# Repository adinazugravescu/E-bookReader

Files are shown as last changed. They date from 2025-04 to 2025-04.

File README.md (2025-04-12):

## Diagrama bloc

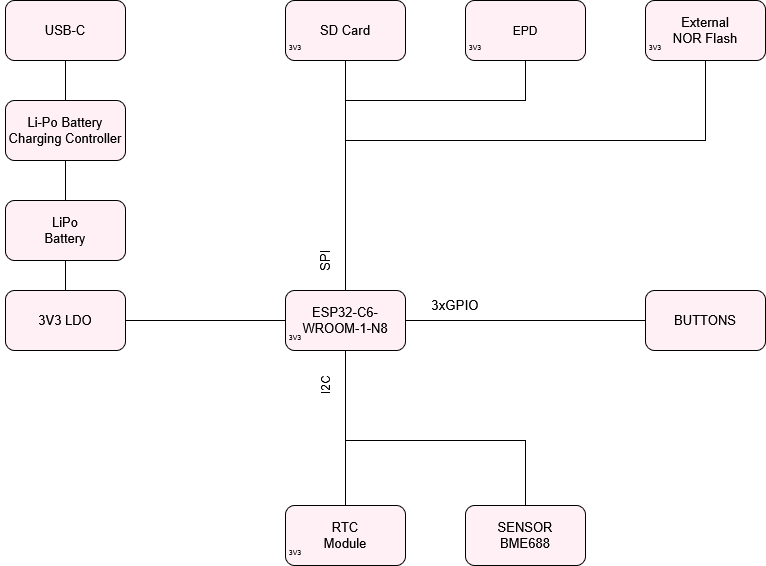
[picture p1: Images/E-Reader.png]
Diagrama bloc


##  Bill of Materials (BOM)

| Componenta/Modul | Link achizitie | Datasheet |
|---|---|---|
| Buton<br/> (*Model descarcat si adaptat*) | [Buy](https://componentsearchengine.com/prices/TSP1C-RA?manufacturer=KNITTER-SWITCH) | [Datasheet](https://docs.rs-online.com/1fd0/0900766b80e2c247.pdf) |
| Condensator 100nF | [Buy](https://ro.mouser.com/ProductDetail/KYOCERA-AVX/04026D104KAT2A?qs=LLG2yGGJ5NhILwMziGI8Xg%3D%3D) | [Datasheet](https://www.mouser.com/catalog/supplier/library/pdf/AVXSurfaceMountCeramic.pdf) |
| CPH3225A(C10_SUPERCAP) | [Buy](https://ro.mouser.com/ProductDetail/Seiko-Semiconductors/CPH3225A?qs=3etwrb1wR%252BhUOph6lAO7eg%3D%3D) | [Datasheet](https://ro.mouser.com/datasheet/2/360/Seiko_Instruments_MicroBattery_E_20230330_2024Jan_-3561061.pdf) |
| Condensator 4.7uF | [Buy](https://ro.mouser.com/ProductDetail/KEMET/C0402C475M7PACTU?qs=SzIX745sIXFB9Q9KfZhc4g%3D%3D) | [Datasheet](https://ro.mouser.com/datasheet/2/447/KEM_C1006_X5R_SMD-3316465.pdf) |
| Tantalum Condensator 100uF | [Buy](https://ro.mouser.com/ProductDetail/KYOCERA-AVX/TAJW107M010RNJ?qs=Wtp%252Bf%2FAeVqIH8v1VxV%252B1Rg%3D%3D) | [Datasheet](https://ro.mouser.com/datasheet/2/40/TAJ-3165264.pdf) |
| Condensator 1uF | [Buy](https://ro.mouser.com/ProductDetail/KYOCERA-AVX/04026D105KAT2A?qs=LLG2yGGJ5NgAzk5fb%252BnzGQ%3D%3D) | [Datasheet](https://ro.mouser.com/datasheet/2/40/cx5r_KGM-3223198.pdf) |
| Condensator 10uF | [Buy](https://www.digikey.com/en/products/detail/venkel/C0402X5R100-106MNP/12327194) | [Datasheet](https://venkelecd.com/partnumber/datasheet/C0402X5R100-106MNP) |
| CHG_LED | [Buy](https://www.kingbrightusa.com/distyPNInv.asp?sltSearch=distyInv&match=1&txtPartNo=APHM1608ECT) | [Datasheet](https://www.kingbrightusa.com/images/catalog/SPEC/APHM1608ECT.pdf) |
| USBLC6-2SC6Y | [Buy](https://ro.mouser.com/ProductDetail/STMicroelectronics/USBLC6-2SC6Y?qs=gNDSiZmRJS%2FOgDexvXkdow%3D%3D) | [Datasheet](https://ro.mouser.com/datasheet/2/389/usblc6_2sc6y-1852505.pdf) |
| PGB1010603MR | [Buy](https://ro.mouser.com/ProductDetail/Littelfuse/PGB1010603MR?qs=gu7KAQ731URLg4GSnNNN7Q%3D%3D) | [Datasheet](https://www.littelfuse.com/assetdocs/pulseguard-esd-suppressors-pgb1-datasheet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) |
| SD0805S020S1R0 | [Buy](https://ro.mouser.com/ProductDetail/KYOCERA-AVX/SD0805S020S1R0?qs=jCA%252BPfw4LHbpkAoSnwrdjw%3D%3D) | [Datasheet](https://ro.mouser.com/datasheet/2/40/schottky-3165252.pdf) |
| MBR0530 | [Buy](https://ro.mouser.com/ProductDetail/onsemi/MBR0530T1G?qs=3JMERSakeboS%2FFOxJUMWeg%3D%3D) | [Datasheet](https://www.onsemi.com/download/data-sheet/pdf/mbr0530t1-d.pdf) |
| Condensator 1uF/50V | [Buy](https://ro.mouser.com/ProductDetail/KYOCERA-AVX/06035D105MAT2A?qs=k4kUdCzLgS5%252BURKe1SOIeQ%3D%3D) | [Datasheet](https://ro.mouser.com/datasheet/2/40/cx5r_KGM-3223198.pdf) |
| Condensator 0.1uF/50V | [Buy](https://ro.mouser.com/ProductDetail/KYOCERA-AVX/04025C104JAT2A?qs=yqaQSyyJnNjAUYBPnTRwrw%3D%3D) | [Datasheet](https://ro.mouser.com/datasheet/2/40/AutoMLCC-2952695.pdf) |
| BD5229G-TR | [Buy](https://ro.mouser.com/ProductDetail/ROHM-Semiconductor/BD5229G-TR?qs=4kLU8WoGk0vvnhrrYwdszw%3D%3D) | [Datasheet](https://fscdn.rohm.com/en/products/databook/datasheet/ic/power/voltage_detector/bd52xxg-e.pdf) |
| XC6220A331MR-G | [Buy](https://ro.mouser.com/ProductDetail/Torex-Semiconductor/XC6220A331MR-G?qs=AsjdqWjXhJ8ZSWznL1J0gg%3D%3D) | [Datasheet](https://ro.mouser.com/datasheet/2/760/xc6220-3371556.pdf) |
| FH34SRJ-24S-0.5SH_99_ | [Buy](https://ro.mouser.com/ProductDetail/Hirose-Connector/FH34SRJ-24S-0.5SH99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) | [Datasheet](https://ro.mouser.com/datasheet/2/185/FH34SRJ_24S_0_5SH_99__CL0580_1255_6_99_2DDrawing_0-1615044.pdf) |
| USB4110-GF-A | [Buy](https://ro.mouser.com/ProductDetail/GCT/USB4110-GF-A?qs=KUoIvG%2F9IlYiZvIXQjyJeA%3D%3D) | [Datasheet](https://ro.mouser.com/datasheet/2/837/GCT_USB4110_Product_Drawing___20k_cycles-3455479.pdf) |
| QWIIC_RIGHT_ANGLE | [Buy](https://ro.mouser.com/ProductDetail/JST-Commercial/SM04B-SRSS-TBLFSN?qs=cdbOS8ANM9B3FdyA6cNU2A%3D%3D) | [Datasheet](https://ro.mouser.com/datasheet/2/564/eSR_SZ-3476820.pdf) |
| 112A-TAAR-R03_ATTEND | [Buy](https://www.tme.eu/ro/details/mcc-sdmicro/conectori-pentru-cartele/attend/112a-taar-r03/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) | [Datasheet](https://www.attend.com.tw/data/download/file/112A-TAAR-R03.pdf) |
| Bobina | [Buy](https://ro.mouser.com/ProductDetail/Wurth-Elektronik/744043680?qs=PGXP4M47uW6VkZq%252BkzjrHA%3D%3D) | [Datasheet](https://www.we-online.com/components/products/datasheet/744043680.pdf) |
| MCP73831 | [Buy](https://ro.mouser.com/ProductDetail/Microchip-Technology/MCP73831T-2ATI-OT?qs=yUQqVecv4qsZbioEUu%252B83g%3D%3D) | [Datasheet](https://ro.mouser.com/datasheet/2/268/MCP73831_Family_Data_Sheet_DS20001984H-3441711.pdf) |
| PFMF.050.1 | [Buy](https://ro.mouser.com/ProductDetail/Schurter/PFMF.050.2?qs=1auRipcfynCums5v1iucSA%3D%3D) | [Datasheet](https://ro.mouser.com/datasheet/2/358/typ_PFMF-1275918.pdf) |
| DMG2305UX-7 | [Buy](https://ro.mouser.com/ProductDetail/Diodes-Incorporated/DMG2305UX-7?qs=L1DZKBg7t5F%2FNBHrjfxC%252Bg%3D%3D) | [Datasheet](https://www.diodes.com/assets/Datasheets/DMG2305UX.pdf) |
| SI1308EDL-T1-GE3 | [Buy](https://ro.mouser.com/ProductDetail/Vishay-Semiconductors/SI1308EDL-T1-GE3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) | [Datasheet](https://www.vishay.com/docs/63399/si1308edl.pdf) |
| Rezistenta 10K | [Buy](https://www.digikey.com/en/products/detail/venkel/CR0402-10W-102JT/12332774) | [Datasheet](https://data.venkel.com/documents/cr-series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.) |
| Rezistenta 200 | [Buy](https://ro.mouser.com/ProductDetail/Vishay-Beyschlag/MCS0402MD2000BE100?qs=3SvaY9RawMJNVte4F12%252BZQ%3D%3D) | [Datasheet](https://www.vishay.com/docs/28952/mcs0402at-mct0603at-mcu0805at-mca1206at.pdf) |
| Rezistenta 100K | [Buy](https://www.digikey.com/en/products/detail/venkel/CR0402-16W-1003FT/12328296) | [Datasheet](https://octopart.com/datasheet/cr0402-16w-1003ft-venkel-16112934) |
| Rezistenta 2.2 | [Buy](https://www.digikey.com/en/products/detail/venkel/TFCR0402-16W-C-1002BT/12331302) | [Datasheet](https://data.venkel.com/documents/tfcr-series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.) |
| Rezistenta 5K1 | [Buy](https://ro.mouser.com/ProductDetail/YAGEO/RT0402BRD075K1L?qs=gY0y7AQI9SOxpEAvlEsiTQ%3D%3D) | [Datasheet](https://ro.mouser.com/datasheet/2/447/PYu_RT_1_to_0_01_RoHS_L_15-3461507.pdf) |
| Rezistenta 2K | [Buy](https://ro.mouser.com/ProductDetail/Bourns/CR0402AFX-2001GLF?qs=GedFDFLaBXEKjamDtfYtIQ%3D%3D) | [Datasheet](https://ro.mouser.com/datasheet/2/54/cr_a-1858337.pdf) |
| Rezistenta 0.47 | [Buy](https://ro.mouser.com/ProductDetail/Vishay-Beyschlag/MMA02040C4707JB000?qs=YmMt7wOBEV42V6C1Rc7zpg%3D%3D) | [Datasheet](https://www.vishay.com/docs/28713/melfprof.pdf) |
| Rezistenta 15 | [Buy](https://ro.mouser.com/ProductDetail/YAGEO/RT0402FRE0715RL?qs=BXCcY9r%252B08DFFpLSkPOIqQ%3D%3D) | [Datasheet](https://ro.mouser.com/datasheet/2/447/PYu_RT_1_to_0_01_RoHS_L_15-3461507.pdf) |
| BME688 | [Buy](https://ro.mouser.com/ProductDetail/Bosch-Sensortec/BME688?qs=IS%252B4QmGtzzqQoVDscqwx3A%3D%3D) | [Datasheet](https://ro.mouser.com/datasheet/2/783/bst_bme688_fl000-2307034.pdf) |
| W25Q512JVEIQ | [Buy](https://ro.mouser.com/ProductDetail/Winbond/W25Q512JVEIQ?qs=l7cgNqFNU1jw6svr3at6tA%3D%3D) | [Datasheet](https://ro.mouser.com/datasheet/2/949/Winbond_W25Q512JV_Datasheet-3240039.pdf) |
| ESP32-C6-WROOM-1-N8 | [Buy](https://ro.mouser.com/ProductDetail/Espressif-Systems/ESP32-C6-WROOM-1-N8?qs=8Wlm6%252BaMh8ST02Gmwp74cw%3D%3D) | [Datasheet](https://ro.mouser.com/datasheet/2/891/Espressif_ESP32_C6_WROOM_1__Datasheet_V0_1_PRELIMI-3239987.pdf) |
| DS3231SN# | [Buy](https://ro.mouser.com/ProductDetail/Analog-Devices-Maxim-Integrated/DS3231SN?qs=1eQvB6Dk1vhUlr8%2FOrV0Fw%3D%3D) | [Datasheet](https://ro.mouser.com/datasheet/2/609/DS3231-3421123.pdf) |
| MAX17048G+T10 | [Buy](https://ro.mouser.com/ProductDetail/Analog-Devices-Maxim-Integrated/MAX17048G%2bT10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) | [Datasheet](https://ro.mouser.com/datasheet/2/609/MAX17048_MAX17049-3469099.pdf) |
| Solder Jumper | [Buy](https://ro.mouser.com/ProductDetail/Vishay-Dale/CRCW04020000Z0EEHP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) | [Datasheet](https://www.vishay.com/docs/20043/crcwhpe3.pdf) |
| Test Pad | [Buy](https://www.digikey.com/en/products/detail/keystone-electronics/5006/255330) | [Datasheet](https://www.keyelco.com/userAssets/file/M65p56.pdf) |
##  Descriere functionalitate hardware

Proiectul este bazat pe un microcontroller **ESP32-C6-WROOM-1-N8**, alimentat printr-un LDO 3V3 dintr-o baterie Li-Po(1800 mAh). Alimentarea este gestionata de un circuit de incarcare **MCP73831** conectat la USB-C. ESP32-C6-WROOM-1-N8 controleaza toate componentele externe prin interfete standard SPI, I2C si GPIO:

- **E-paper Display** – conectat prin **SPI**
- **SD Card** – **SPI**, pentru stocare
- **NOR Flash** – **SPI**, memorie externa
- **RTC DS3231SN#** – conectat prin **I2C** pentru ceas de timp real
- **SENSOR2 BME688** – senzor de mediu conectat pe aceeasi magistrala **I2C**
- **RESET&BOOT/IO** – conectate prin GPIO
- **Qwiic/Stemma QT** – extensie I2C pentru senzori/modul aditionali
- **Test Pads** – pentru TX/RX UART + debugging hardware

Comunicarea cu display-ul si stocarea se face prin interfete rapide SPI. Toate componentele I2C partajeaza linia SDA si SCL, pentru a minimiza utilizarea pinilor.

**Specificatii electronice componente principale**

   - Microcontroller – ESP32-C6-WROOM-1-N8 CPU: 32-bit RISC-V single-core, frecventa maxima 160 MHz. Memorie interna: 320KB ROM, 512KB HP SRAM, 16KB LP SRAM. Conectivitate: Wi-Fi 6 si Bluetooth LE 5.0. Tensiune de operare: 3.3V. Consum de curent: 160–260 mA in mod activ, 3–20 mA in modem-sleep, 0.8 mA in light-sleep, 10 µA in deep-sleep, 2.5 µA in hibernare.

   - Display – E-paper 7.5": Display de tip ePaper, ales pentru consumul extrem de redus si lizibilitatea foarte buna in lumina naturala.

   - Memorie: Stocarea este realizata cu un card MicroSD si un cip NOR Flash de 64MB conectat pe aceeasi magistrala SPI.

   - Senzor ambiental – BME688: Senzor digital care masoara temperatura, umiditatea, presiunea si compozitia gazelor.Tensiune de alimentare: 1.71V – 3.6V. Consum: <1 mA in mod activ, <1 µA in mod sleep.

   - Regulator tensiune – XC6220A331MR-G: LDO pentru conversia tensiunii bateriei la 3.3V. Curent maxim de iesire: 700 mA. Tensiune de cadere: aprox. 250 mV la 500 mA.

   - Circuit incarcare baterie – MCP73831: Controller linear pentru incarcare acumulatori Li-Po. Tensiune intrare: 3.75V – 6V. Curent maxim programabil pana la 500 mA.

##  Utilizarea pinilor ESP32-C6

| Componenta | Pin ESP32-C6 | Functie | Justificare |
|---|---|---|---|
| **EPD** | IO7 | MOSI | Pin dedicat SPI pentru date, permite viteza mare de transfer |
| | IO6 | SCK | Clock SPI standard |
| | IO10 | EPD_CS | Linie de selectare pentru e-paper |
| | IO5 | EPD_DC | Selecteaza intre comanda si date trimise |
| | IO3 | EPD_BUSY | Citire stare de ocupare a display-ului |
| | IO23 | EPD_RST | Reset hardware |
| **SD Card** | IO6 | SCK | Linie separata CS pentru SD card |
| | IO2 | MISO | Linie unica pentru citirea datelor |
| | IO7 | MOSI | Linie partajata de scriere |
| | IO4 | SS_SD | Linie de chip select pentru SD card |
| **NOR Flash** | IO2 | MISO | Linie CS separata pentru memoria Flash |
| | IO7 | MOSI | Linie partajata de scriere |
| | IO11 | FLASH_CS | Selectare separata a chipului de memorie |
| | IO6 | SCK | Clock SPI comun |
| **RTC DS3231SN** | IO21 | SDA | Linie I2C standard pentru date |
| | IO22 | SCL | Linie I2C standard pentru ceas |
| | IO18 | RTC_RST | Reset software controlabil pentru RTC |
| | IO0 | INT_RTC | Wake-up de la RTC |
| | IO1 | 32KHZ | Iesire frecventa |
| **BME688** | IO21 | SDA | I2C partajat |
| | IO22 | SCL | I2C partajat |
| | IO19 | I2C_PW | Control alimentare senzor |
| **Qwiic** | IO21 / IO22  | SDA/SCL | ~ |
| **E-paper Power**  | IO20 | EPD_3V3_C | Activeaza alimentarea prin tranzistor |
| **BOOT Button** | IO9 | IO/BOOT | Pin standard pentru intrare in modul flash |
| **CHANGE Button**  | IO15 | IO/CHANGE | Permite comutarea intre modurile de functionare |
| **RESET Button** | EN | RESET | Pin hardware de reset (activ LOW) |
| **UART Debug** | GPIO16 | TX (TXD0) | Pentru debug/programare |
| | GPIO17 | RX (RXD0) | Pentru debug/programare |
| **USB** | IO12, IO13 | USB D- / D+ | Comunicare USB-C |

---
## Etapele implementarii proiectului

1. **Realizarea schematicului**  
   Am creat schema electrica pe baza modelului oferit, utilizand componentele si simbolurile din biblioteca furnizata. Am avut grija sa respect toate cerintele tehnice si sa evit erorile de ERC. Avertismentele ramase au fost acceptate, deoarece reies direct din structura impusa de model.

2. **Proiectarea PCB-ului**  
   Am trecut in modul PCB, unde am plasat toate componentele pe stratul top, conform pozitiei si dimensiunilor impuse. Am decupat antena modulului ESP32-C6 si am pozitionat corect toate elementele, astfel incat sa incapa in carcasa.

3. **Rutarea si planul de masa**  
   Am realizat rutarea pe baza constrangerilor din tema, am aplicat plan de masa atat pe stratul top, cat si pe stratul bottom, si am adaugat via stitching intre cele doua straturi pentru integritate electrica .

4. **Adaugarea informatiilor de productie**  
   Am etichetat toate componentele pe silkscreen pentru o vizualizare clara in 3D si pentru productie.

5. **Integrarea modelelor 3D**  
   Am importat modelele 3D corespunzatoare pentru fiecare componenta in parte si le-am creat modelele 3D.

6. **Modelarea carcasei**  
   Am adaptat carcasa astfel incat placa sa se potriveasca perfect in interior, respectand cerintele mecanice de montaj.

7. **Constructia componentelor externe**  
   Am construit modelul 3D al bateriei si al display-ului conform dimensiunilor si detaliilor din datasheet-urile oferite.

###  Probleme intampinate

- Gasirea unui model 3D compatibil cu footprint-ul butonului a fost dificila, asa ca am modificat manual un model descarcat.
- In schematic, anumite warning-uri au fost acceptate deoarece erau implicite in structura designului cerut.
- Au fost acceptate cele doua erori DRC aparute la mufa USB, conform instructiunilor primite.

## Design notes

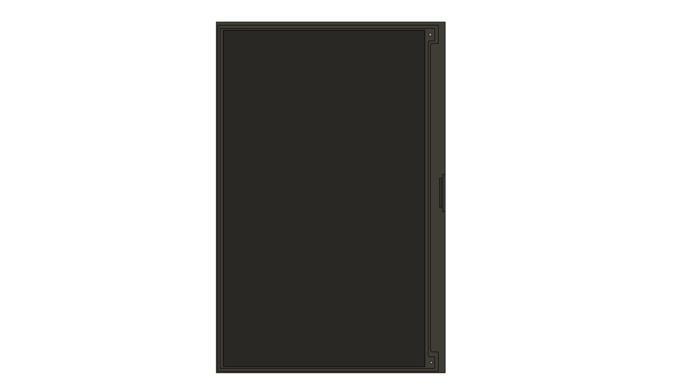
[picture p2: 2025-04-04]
Images/DISPLAY(1).png

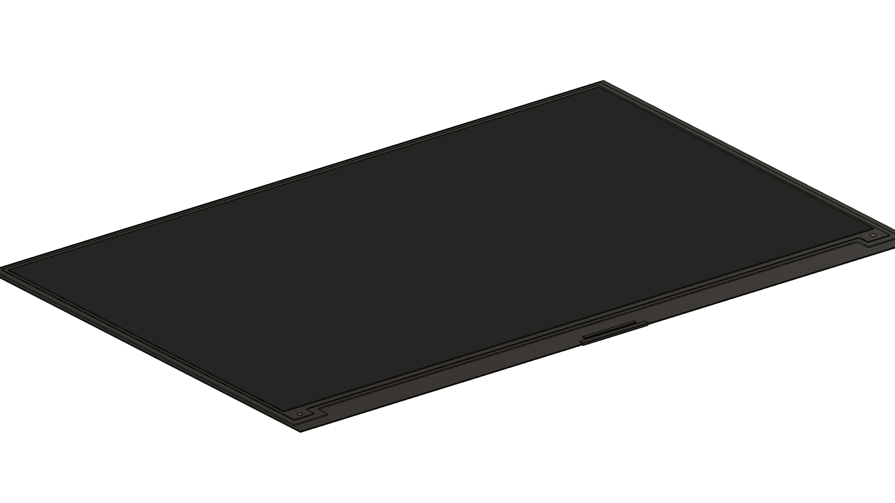
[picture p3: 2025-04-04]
Images/DISPLAY(2).png

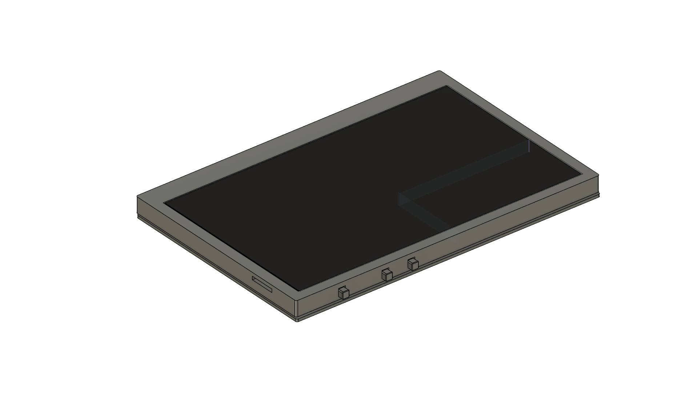
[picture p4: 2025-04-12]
Images/DEVICE(1).png

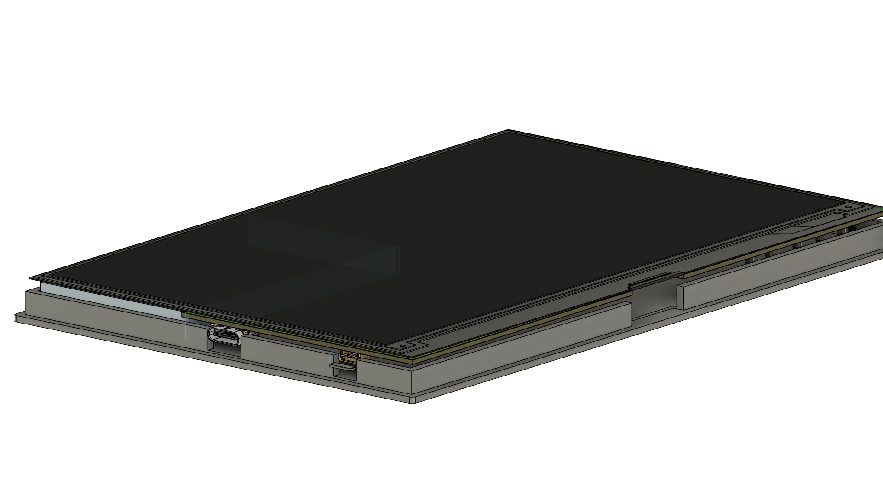
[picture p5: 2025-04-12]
Images/DEVICE(5).png

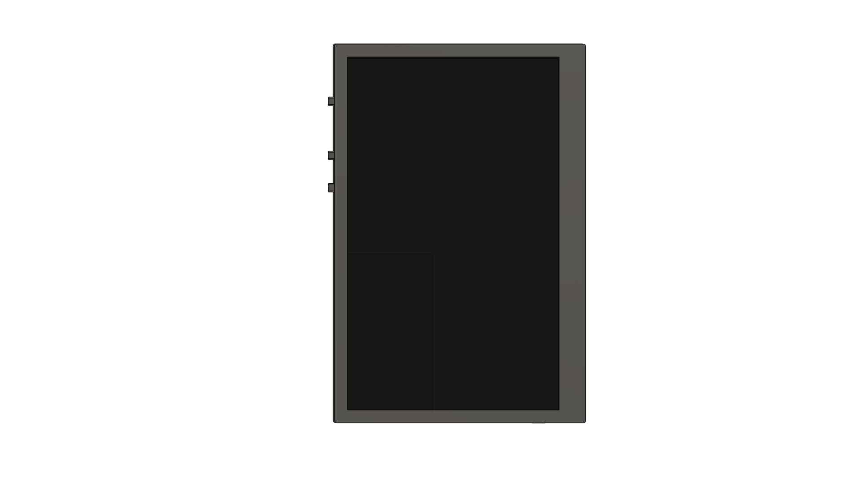
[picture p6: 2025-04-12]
Images/DEVICE(3).png

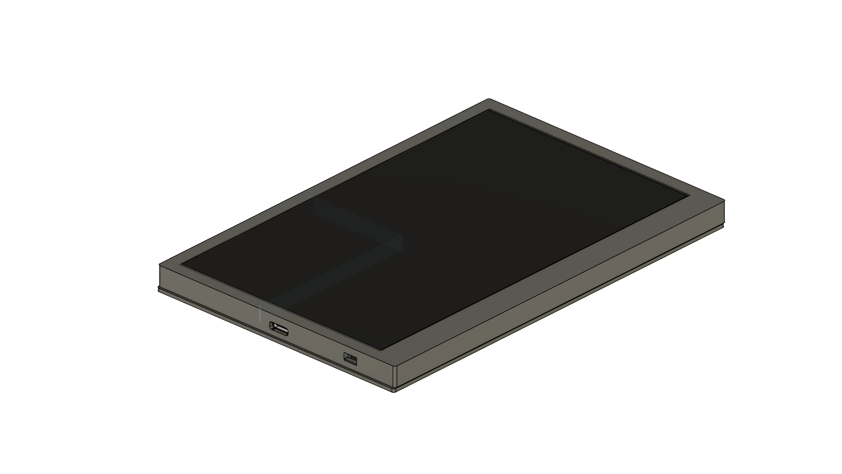
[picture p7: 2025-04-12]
Images/DEVICE(2).png

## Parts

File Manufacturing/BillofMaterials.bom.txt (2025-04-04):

Designator                      Comment Footprint
BOOT_BUTTON	49.03	108.83	180.00	BUTTON_CUSYOMV1	MYBUTTON
C1	155.24	5.93	90.00	100nF	EAGLE-LTSPICE_C0402
C10	67.74	108.31	90.00	100nF	EAGLE-LTSPICE_C0402
C10_SUPERCAP	96.49	50.94	270.00	CPH3225A	CAPCP3225X100N
C1_BAT	121.93	51.15	0.00	4.7uF	EAGLE-LTSPICE_C0402
C1_BAT1	122.28	38.37	180.00	4.7uF	EAGLE-LTSPICE_C0402
C1_BAT2	134.52	41.37	90.00	4.7uF	EAGLE-LTSPICE_C0402
C2	156.72	5.93	90.00	100nF	EAGLE-LTSPICE_C0402
C2_BAT	133.64	52.85	90.00	4.7uF	EAGLE-LTSPICE_C0402
C3	131.31	40.30	270.00	100uF TANT	RCL_CT3528
C4	92.31	30.59	90.00	4.7uF/25V	EAGLE-LTSPICE_C0402
C4_USB	152.63	48.07	0.00	100nF	EAGLE-LTSPICE_C0402
C5	27.61	108.31	90.00	1uF	EAGLE-LTSPICE_C0402
C5_USB	152.64	46.57	0.00	4.7uF	EAGLE-LTSPICE_C0402
C6	45.30	108.21	90.00	100nF	EAGLE-LTSPICE_C0402
C7	79.79	22.63	0.00	10uF	EAGLE-LTSPICE_C0402
C8	87.48	47.33	0.00	100nF	EAGLE-LTSPICE_C0402
C9	7.06	99.53	90.00	100nF	EAGLE-LTSPICE_C0402
CHANGE_BUTTON	64.06	108.83	180.00	BUTTON_CUSYOMV1	MYBUTTON
CHG_LED	125.44	51.15	90.00		ADAFRUIT_CHIP-LED0603
C_DELAY	52.57	100.99	90.00	100nF	EAGLE-LTSPICE_C0402
D1	151.98	50.97	0.00	USBLC6-2SC6Y	SOT95P280X145-6N
D10	46.22	37.77	270.00	PGB1010603MR	DIOC1608X36N
D11	49.70	37.77	90.00	PGB1010603MR	DIOC1608X36N
D12	51.58	37.77	90.00	PGB1010603MR	DIOC1608X36N
D2	121.49	41.58	90.00	ESP32_WROVER_AVX---SD0805S020S1R0_AVX_SD0805S020S1R0_0_0AVX_SD0805S020S1R0_0_0	ESP32_WROVER_AVX---SD0805S020S1R0_AVX_SD0805S020S1R0_0
D3	88.56	26.57	0.00	MBR0530	SOD3716X135N
D4	81.52	33.78	180.00	MBR0530	SOD3716X135N
D5	88.54	29.98	180.00	MBR0530	SOD3716X135N
D6	74.28	21.07	0.00	PGB1010603MR	DIOC1608X36N
D7	88.24	63.28	0.00	ESP32_WROVER_AVX---SD0805S020S1R0_AVX_SD0805S020S1R0_0_0AVX_SD0805S020S1R0_0_0	ESP32_WROVER_AVX---SD0805S020S1R0_AVX_SD0805S020S1R0_0
D8	15.26	98.77	0.00	PGB1010603MR	DIOC1608X36N
D9	35.94	46.77	90.00	PGB1010603MR	DIOC1608X36N
EPD_C1	68.85	19.77	90.00	1uF/50V	EAGLE-LTSPICE_C0402
EPD_C10	85.51	19.89	90.00	1uF/50V	EAGLE-LTSPICE_C0402
EPD_C11	87.09	19.89	90.00	1uF/50V	EAGLE-LTSPICE_C0402
EPD_C12	88.75	19.89	90.00	1uF/50V	EAGLE-LTSPICE_C0402
EPD_C2	70.48	19.75	90.00	1uF/50V	EAGLE-LTSPICE_C0402
EPD_C5	77.05	19.89	90.00	0.1uF/50V	EAGLE-LTSPICE_C0402
EPD_C6	78.69	19.85	90.00	1uF/50V	EAGLE-LTSPICE_C0402
EPD_C7	80.40	19.85	90.00	1uF/50V	EAGLE-LTSPICE_C0402
EPD_C8	82.11	19.85	90.00	1uF/50V	EAGLE-LTSPICE_C0402
EPD_C9	83.72	19.85	90.00	1uF/50V	EAGLE-LTSPICE_C0402
IC1	49.25	100.67	0.00	BD5229G-TR	SOT95P280X125-5N
IC4	126.03	41.39	0.00	XC6220A331MR-G	SOT95P280X120-5N
J1	83.07	13.94	0.00	FH34SRJ-24S-0.5SH_99_	FH34SRJ24S05SH99
J2	165.93	54.30	90.00	SAMACSYS_PARTS_USB4110-GF-A	SAMACSYS_PARTS_USB4110GFA
J3	166.35	19.30	90.00	QWIIC_RIGHT_ANGLE	JST04_1MM_RA
J4	9.09	88.95	270.00	112A-TAAR-R03_ATTEND	112ATAARR03ATTEND
L1	81.50	28.20	270.00	68uH	IND_4828-WE-TPC_WRE
MCP73831	129.15	50.59	90.00	ESP32_WROVER_SPARKFUN-IC-POWER_MCP73831	ESP32_WROVER_SPARKFUN-IC-POWER_SOT23-5
PFMF.050.1	151.04	43.50	0.00	ESP32C6_VARISTORCN1812	ESP32C6_VARISTOR_CT/CN1812
Q1	136.06	47.31	0.00	20V/4.2A/52mΩ/1.4W	ESP32_WROVER_SPARKFUN-DISCRETESEMI_SOT23-3
Q2	76.53	23.76	270.00	20V/4.2A/52mΩ/1.4W	ESP32_WROVER_SPARKFUN-DISCRETESEMI_SOT23-3
Q3	63.69	18.38	90.00	SI1308EDL-T1-GE3	SOT65P210X110-3N
R1	19.45	40.33	90.00	10K	ESP32_WROVER_EAGLE-LTSPICE_R0402
R10	8.43	99.53	90.00	10K	ESP32_WROVER_EAGLE-LTSPICE_R0402
R1_BAT	125.25	49.55	0.00	200	ESP32_WROVER_EAGLE-LTSPICE_R0402
R1_PINH	152.16	5.97	90.00	10K	ESP32_WROVER_EAGLE-LTSPICE_R0402
R1_PINH1	88.26	61.64	0.00	10K	ESP32_WROVER_EAGLE-LTSPICE_R0402
R1_PWRUSB	119.55	41.64	90.00	100K	ESP32_WROVER_EAGLE-LTSPICE_R0402
R2	62.73	13.21	0.00	2.2	ESP32_WROVER_EAGLE-LTSPICE_R0402
R2-PINH	153.72	5.97	90.00	10K	ESP32_WROVER_EAGLE-LTSPICE_R0402
R2-PINH1	92.43	60.19	90.00	10K	ESP32_WROVER_EAGLE-LTSPICE_R0402
R2-USB	154.98	52.83	90.00	5K1	ESP32_WROVER_EAGLE-LTSPICE_R0402
R2-USB1	147.90	51.17	90.00	5K1	ESP32_WROVER_EAGLE-LTSPICE_R0402
R2_BAT	127.86	46.85	90.00	2K	ESP32_WROVER_EAGLE-LTSPICE_R0402
R3	65.11	12.23	90.00	0.47	ESP32_WROVER_EAGLE-LTSPICE_R0402
R4	66.89	17.11	0.00	10K	ESP32_WROVER_EAGLE-LTSPICE_R0402
R5	33.81	46.78	268.50	10K	ESP32_WROVER_EAGLE-LTSPICE_R0402
R6	46.43	34.21	90.00	10K	ESP32_WROVER_EAGLE-LTSPICE_R0402
R7	49.65	34.21	90.00	10K	ESP32_WROVER_EAGLE-LTSPICE_R0402
R8	51.67	34.21	90.00	10K	ESP32_WROVER_EAGLE-LTSPICE_R0402
R9	71.99	23.81	90.00	10K	ESP32_WROVER_EAGLE-LTSPICE_R0402
RESET_BUTTON	23.95	108.83	180.00	BUTTON_CUSYOMV1	MYBUTTON
R_BOOT	52.71	108.31	90.00	10K	ESP32_WROVER_EAGLE-LTSPICE_R0402
R_CAPACITOR	93.55	50.64	90.00	15	ESP32_WROVER_EAGLE-LTSPICE_R0402
R_CHANGE	60.42	108.24	90.00	10K	ESP32_WROVER_EAGLE-LTSPICE_R0402
R_CL1	73.86	23.73	90.00	10K	ESP32_WROVER_EAGLE-LTSPICE_R0402
R_RESET	20.29	108.31	90.00	10K	ESP32_WROVER_EAGLE-LTSPICE_R0402
SENSOR2	154.72	11.32	90.00	BME688	ESP32_WROVER_BME680_PSON80P300X300X100-8N
SJ1	62.36	11.29	0.00		SJ
TP1	3.01	30.69	0.00	TPTP20R	TP20R
TP10	14.38	2.91	0.00	TPTP20R	TP20R
TP11	22.09	2.89	0.00	TPTP20R	TP20R
TP12	30.03	3.01	0.00	TPTP20R	TP20R
TP13	39.68	3.11	0.00	TPTP20R	TP20R
TP14	143.13	64.01	0.00	TPTP20R	TP20R
TP15	84.68	96.61	0.00	TPTP20R	TP20R
TP16	84.93	90.21	0.00	TPTP20R	TP20R
TP17	47.08	2.91	0.00	TPTP20R	TP20R
TP2	2.88	25.79	0.00	TPTP20R	TP20R
TP3	148.25	63.99	0.00	TPTP20R	TP20R
TP4	81.37	102.89	0.00	TPTP20R	TP20R
TP5	87.99	102.89	0.00	TPTP20R	TP20R
TP6	3.01	20.29	0.00	TPTP20R	TP20R
TP7	6.63	16.49	0.00	TPTP20R	TP20R
TP8	6.75	11.39	0.00	TPTP20R	TP20R
TP9	6.87	5.99	0.00	TPTP20R	TP20R
U1	39.59	52.96	0.00	W25Q512JVEIQ	SON127P600X800X80-9N
U2	16.30	52.71	90.00	ESP32-C6-WROOM-1-N8	XCVR_ESP32-C6-WROOM-1-N8
U3	84.85	54.90	270.00	DS3231SN#	SOIC127P1032X265-16N
U4	139.04	53.12	0.00	MAX17048G+T10	SON50P200X200X80-9N

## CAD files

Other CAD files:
Mechanical/E-Reader(PCB+BATTERY+DISPLAY+CASE).f3z

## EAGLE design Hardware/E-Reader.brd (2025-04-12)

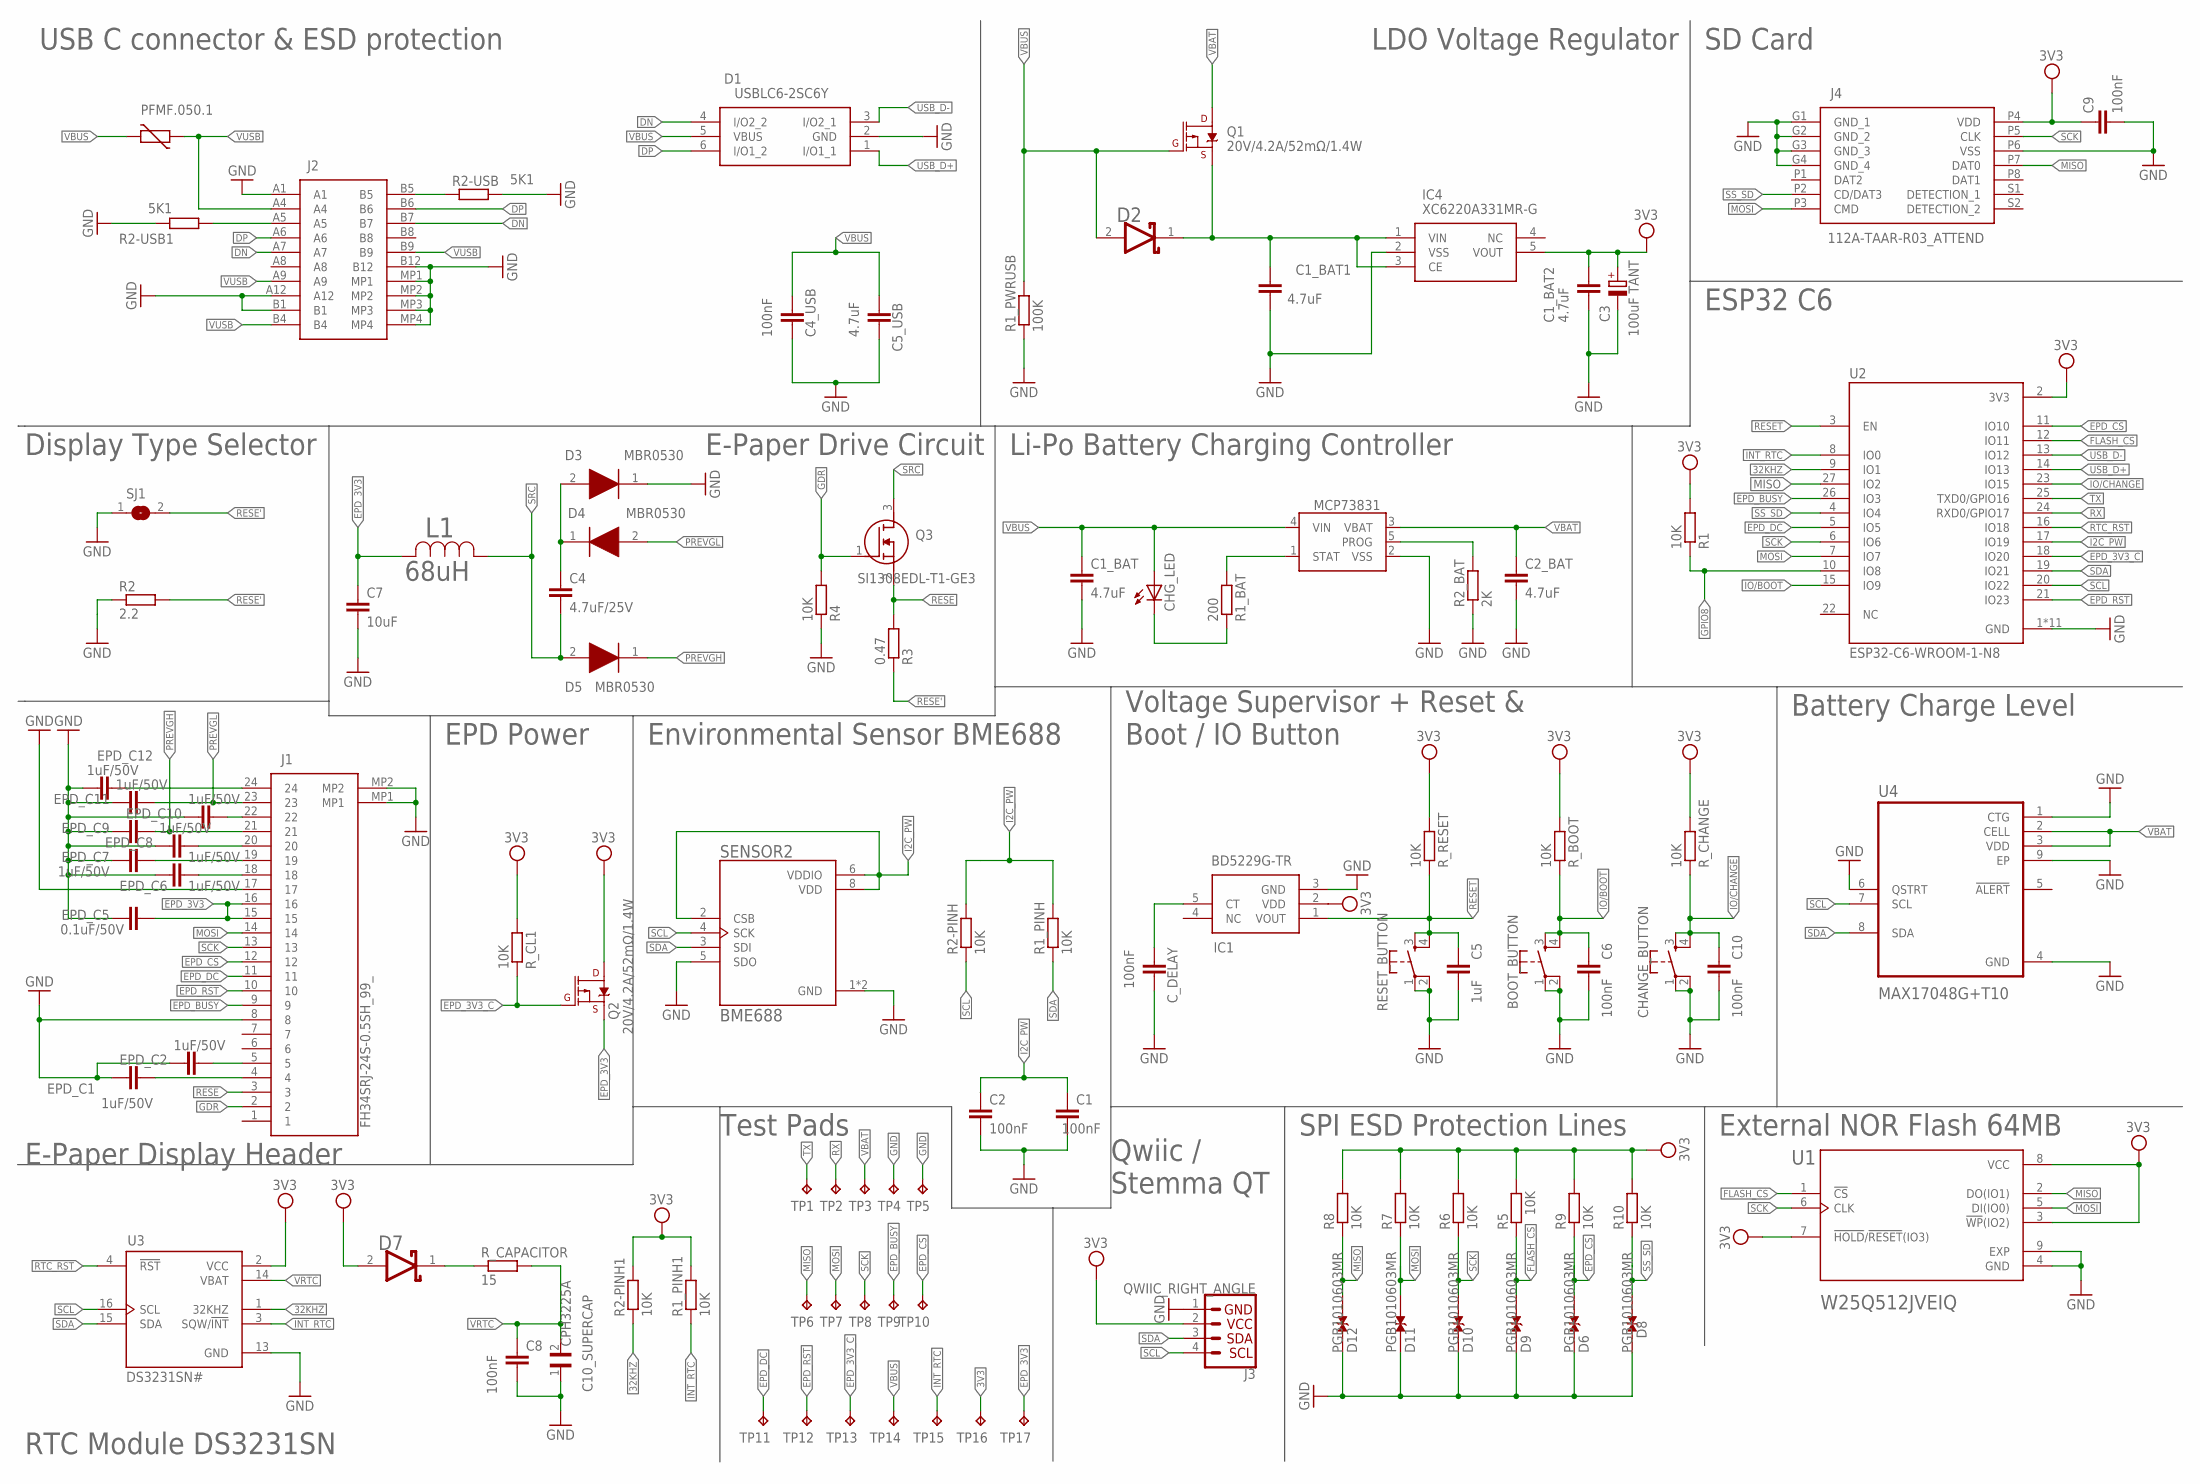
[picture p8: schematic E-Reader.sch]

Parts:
BOOT_BUTTON: BUTTON_CUSYOMV1; MYBUTTON
C1, C2, C4_USB, C6, C8, C9, C10: 100nF; EAGLE-LTSPICE_C0402
C1_BAT, C1_BAT1, C1_BAT2, C2_BAT, C5_USB: 4.7uF; EAGLE-LTSPICE_C0402
C3: 100uF TANT; RCL_CT3528
C4: 4.7uF/25V; EAGLE-LTSPICE_C0402
C5: 1uF; EAGLE-LTSPICE_C0402
C7: 10uF; EAGLE-LTSPICE_C0402
C10_SUPERCAP: CPH3225A; CAPCP3225X100N
CHANGE_BUTTON: BUTTON_CUSYOMV1; MYBUTTON
CHG_LED: ADAFRUIT_LEDCHIP-LED0603; ADAFRUIT_CHIP-LED0603
C_DELAY: 100nF; EAGLE-LTSPICE_C0402
D1: USBLC6-2SC6Y; SOT95P280X145-6N
D2, D7: ESP32_WROVER_AVX---SD0805S020S1R0_AVX_SD0805S020S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; ESP32_WROVER_AVX---SD0805S020S1R0_AVX_SD0805S020S1R0_0
D3, D4, D5: MBR0530; SOD3716X135N
D6, D8, D9, D10, D11, D12: PGB1010603MR; DIOC1608X36N
EPD_C1, EPD_C2, EPD_C6, EPD_C7, EPD_C8, EPD_C9, EPD_C10, EPD_C11, EPD_C12: 1uF/50V; EAGLE-LTSPICE_C0402
EPD_C5: 0.1uF/50V; EAGLE-LTSPICE_C0402
IC1: BD5229G-TR; SOT95P280X125-5N
IC4: XC6220A331MR-G; SOT95P280X120-5N
J1: FH34SRJ-24S-0.5SH_99_; FH34SRJ24S05SH99
J2: SAMACSYS_PARTS_USB4110-GF-A; SAMACSYS_PARTS_USB4110GFA
J3: QWIIC_RIGHT_ANGLE; JST04_1MM_RA
J4: 112A-TAAR-R03_ATTEND; 112ATAARR03ATTEND
L1: 68uH; IND_4828-WE-TPC_WRE
MCP73831: ESP32_WROVER_SPARKFUN-IC-POWER_MCP73831; ESP32_WROVER_SPARKFUN-IC-POWER_SOT23-5
PFMF.050.1: ESP32C6_VARISTORCN1812; ESP32C6_VARISTOR_CT/CN1812
Q1, Q2: 20V/4.2A/52mΩ/1.4W; ESP32_WROVER_SPARKFUN-DISCRETESEMI_SOT23-3
Q3: SI1308EDL-T1-GE3; SOT65P210X110-3N
R1, R1_PINH, R1_PINH1, R2-PINH, R2-PINH1, R4, R5, R6, R7, R8, R9, R10: 10K; ESP32_WROVER_EAGLE-LTSPICE_R0402
R1_BAT: 200; ESP32_WROVER_EAGLE-LTSPICE_R0402
R1_PWRUSB: 100K; ESP32_WROVER_EAGLE-LTSPICE_R0402
R2: 2.2; ESP32_WROVER_EAGLE-LTSPICE_R0402
R2-USB, R2-USB1: 5K1; ESP32_WROVER_EAGLE-LTSPICE_R0402
R2_BAT: 2K; ESP32_WROVER_EAGLE-LTSPICE_R0402
R3: 0.47; ESP32_WROVER_EAGLE-LTSPICE_R0402
RESET_BUTTON: BUTTON_CUSYOMV1; MYBUTTON
R_BOOT: 10K; ESP32_WROVER_EAGLE-LTSPICE_R0402
R_CAPACITOR: 15; ESP32_WROVER_EAGLE-LTSPICE_R0402
R_CHANGE: 10K; ESP32_WROVER_EAGLE-LTSPICE_R0402
R_CL1: 10K; ESP32_WROVER_EAGLE-LTSPICE_R0402
R_RESET: 10K; ESP32_WROVER_EAGLE-LTSPICE_R0402
SENSOR2: BME688; ESP32_WROVER_BME680_PSON80P300X300X100-8N
SJ1: SJ
TP1, TP2, TP3, TP4, TP5, TP6, TP7, TP8, TP9, TP10, TP11, TP12, TP13, TP14, TP15, TP16, TP17: TPTP20R; TP20R
U1: W25Q512JVEIQ; SON127P600X800X80-9N
U2: ESP32-C6-WROOM-1-N8; XCVR_ESP32-C6-WROOM-1-N8
U3: DS3231SN#; SOIC127P1032X265-16N
U4: MAX17048G+T10; SON50P200X200X80-9N

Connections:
3V3: C1_BAT2.1, C3.+, C9.1, D7.2 (ANODE), IC1.2 (VDD), IC4.5 (VOUT), J3.2, J4.P4 (VDD), Q2.3 (D), R1.2, R1_PINH1.2, R2-PINH1.2, R5.2, R6.2, R7.2, R8.2, R9.2, R10.2, R_BOOT.2, R_CHANGE.2, R_CL1.2, R_RESET.2, TP16.TP, U1.3 (!WP!(IO2)), U1.7 (!HOLD!/!RESET!(IO3)), U1.8 (VCC), U2.2 (3V3), U3.2 (VCC)
32KHZ: R2-PINH1.1, U2.9 (IO1), U3.1 (32KHZ)
DN: D1.4 (I/O2_2), J2.A7, J2.B7
DP: D1.6 (I/O1_2), J2.A6, J2.B6
EPD_3V3: C7.1, EPD_C5.2, J1.15, J1.16, L1.2, Q2.2 (S), TP17.TP
EPD_3V3_C: Q2.1 (G), R_CL1.1, TP13.TP, U2.18 (IO20)
EPD_BUSY: J1.9, TP9.TP, U2.26 (IO3)
EPD_CS: D6.2, J1.12, R9.1, TP10.TP, U2.11 (IO10)
EPD_DC: J1.11, TP11.TP, U2.5 (IO5)
EPD_RST: J1.10, TP12.TP, U2.21 (IO23)
FLASH_CS: D9.2, R5.1, U1.1 (!CS), U2.12 (IO11)
GDR: J1.2, Q3.1 (G), R4.2
GND: BOOT_BUTTON.1, BOOT_BUTTON.2, C1.2, C1_BAT.2, C1_BAT1.2, C1_BAT2.2, C2.2, C2_BAT.2, C3.-, C4_USB.2, C5.2, C5_USB.2, C6.2, C7.2, C8.2, C9.2, C10.2, C10_SUPERCAP.1, CHANGE_BUTTON.1, CHANGE_BUTTON.2, C_DELAY.2, D1.2 (GND), D3.1 (K), D6.1, D8.1, D9.1, D10.1, D11.1, D12.1, EPD_C1.1, EPD_C2.1, EPD_C5.1, EPD_C6.1, EPD_C7.1, EPD_C8.1, EPD_C9.1, EPD_C10.1, EPD_C11.1, EPD_C12.1, IC1.3 (GND), IC4.2 (VSS), J1.8, J1.17, J1.MP1, J1.MP2, J2.A1, J2.A12, J2.B1, J2.B12, J2.MP1, J2.MP2, J2.MP3, J2.MP4, J3.1, J4.G1 (GND_1), J4.G2 (GND_2), J4.G3 (GND_3), J4.G4 (GND_4), J4.P6 (VSS), MCP73831.2 (VSS), R1_PWRUSB.1, R2.1, R2-USB.2, R2-USB1.1, R2_BAT.1, R4.1, RESET_BUTTON.1, RESET_BUTTON.2, SENSOR2.1 (GND), SENSOR2.5 (SDO), SENSOR2.7 (GND), SJ1.1, TP4.TP, TP5.TP, U1.4 (GND), U1.9 (EXP), U2.1 (GND), U2.28 (GND), U2.29_1 (GND), U2.29_2 (GND), U2.29_3 (GND), U2.29_4 (GND), U2.29_5 (GND), U2.29_6 (GND), U2.29_7 (GND), U2.29_8 (GND), U2.29_9 (GND), U3.13 (GND), U4.1 (CTG), U4.4 (GND), U4.6 (QSTRT), U4.9 (EP)
GPIO8: R1.1, U2.10 (IO8)
I2C_PW: C1.1, C2.1, R1_PINH.2, R2-PINH.2, SENSOR2.2 (CSB), SENSOR2.6 (VDDIO), SENSOR2.8 (VDD), U2.17 (IO19)
INT_RTC: R1_PINH1.1, TP15.TP, U2.8 (IO0), U3.3 (SQW/!INT)
IO/BOOT: BOOT_BUTTON.3, BOOT_BUTTON.4, C6.1, R_BOOT.1, U2.15 (IO9)
IO/CHANGE: C10.1, CHANGE_BUTTON.3, CHANGE_BUTTON.4, R_CHANGE.1, U2.23 (IO15)
MISO: D12.2, J4.P7 (DAT0), R8.1, TP6.TP, U1.2 (DO(IO1)), U2.27 (IO2)
MOSI: D11.2, J1.14, J4.P3 (CMD), R7.1, TP7.TP, U1.5 (DI(IO0)), U2.7 (IO7)
unnamed: C1_BAT1.1, D2.1 (CATHODE), IC4.1 (VIN), IC4.3 (CE), Q1.2 (S)
unnamed: MCP73831.5 (PROG), R2_BAT.2
unnamed: MCP73831.1 (STAT), R1_BAT.2
unnamed: CHG_LED.C, R1_BAT.1
unnamed: C_DELAY.1, IC1.5 (CT)
unnamed: EPD_C6.2, J1.18
unnamed: C4.1, D3.2 (A), D4.1 (K)
unnamed: EPD_C7.2, J1.19
unnamed: EPD_C1.2, J1.4
unnamed: EPD_C2.2, J1.5
unnamed: D7.1 (CATHODE), R_CAPACITOR.1
unnamed: EPD_C8.2, J1.20
unnamed: J2.B5, R2-USB.1
unnamed: EPD_C10.2, J1.22
unnamed: J2.A5, R2-USB1.2
unnamed: EPD_C12.2, J1.24
PREVGH: D5.1 (K), EPD_C9.2, J1.21
PREVGL: D4.2 (A), EPD_C11.2, J1.23
RESE: J1.3, Q3.2 (S), R3.2
RESE': R2.2, R3.1, SJ1.2
RESET: C5.1, IC1.1 (VOUT), RESET_BUTTON.3, RESET_BUTTON.4, R_RESET.1, U2.3 (EN)
RTC_RST: U2.16 (IO18), U3.4 (!RST)
RX: TP2.TP, U2.24 (RXD0/GPIO17)
SCK: D10.2, J1.13, J4.P5 (CLK), R6.1, TP8.TP, U1.6 (CLK), U2.6 (IO6)
SCL: J3.4, R2-PINH.1, SENSOR2.4 (SCK), U2.20 (IO22), U3.16 (SCL), U4.7 (SCL)
SDA: J3.3, R1_PINH.1, SENSOR2.3 (SDI), U2.19 (IO21), U3.15 (SDA), U4.8 (SDA)
SRC: C4.2, D5.2 (A), L1.1, Q3.3 (D)
SS_SD: D8.2, J4.P2 (CD/DAT3), R10.1, U2.4 (IO4)
TX: TP1.TP, U2.25 (TXD0/GPIO16)
USB_D+: D1.1 (I/O1_1), U2.14 (IO13)
USB_D-: D1.3 (I/O2_1), U2.13 (IO12)
VBAT: C2_BAT.1, MCP73831.3 (VBAT), Q1.3 (D), TP3.TP, U4.2 (CELL), U4.3 (VDD)
VBUS: C1_BAT.1, C4_USB.1, C5_USB.1, CHG_LED.A, D1.5 (VBUS), D2.2 (ANODE), MCP73831.4 (VIN), PFMF.050.1.2, Q1.1 (G), R1_PWRUSB.2, TP14.TP
VRTC: C8.1, C10_SUPERCAP.2, R_CAPACITOR.2, U3.14 (VBAT)
VUSB: J2.A4, J2.A9, J2.B4, J2.B9, PFMF.050.1.1

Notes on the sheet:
USB C connector & ESD protection
LDO Voltage Regulator
SD Card
ESP32 C6
Li-Po Battery Charging Controller
E-Paper Drive Circuit
Display Type Selector
E-Paper Display Header
EPD Power
Environmental Sensor BME688
Voltage Supervisor + Reset & Boot / IO Button
Battery Charge Level
External NOR Flash 64MB
SPI ESD Protection Lines
Qwiic / Stemma QT
Test Pads
RTC Module DS3231SN

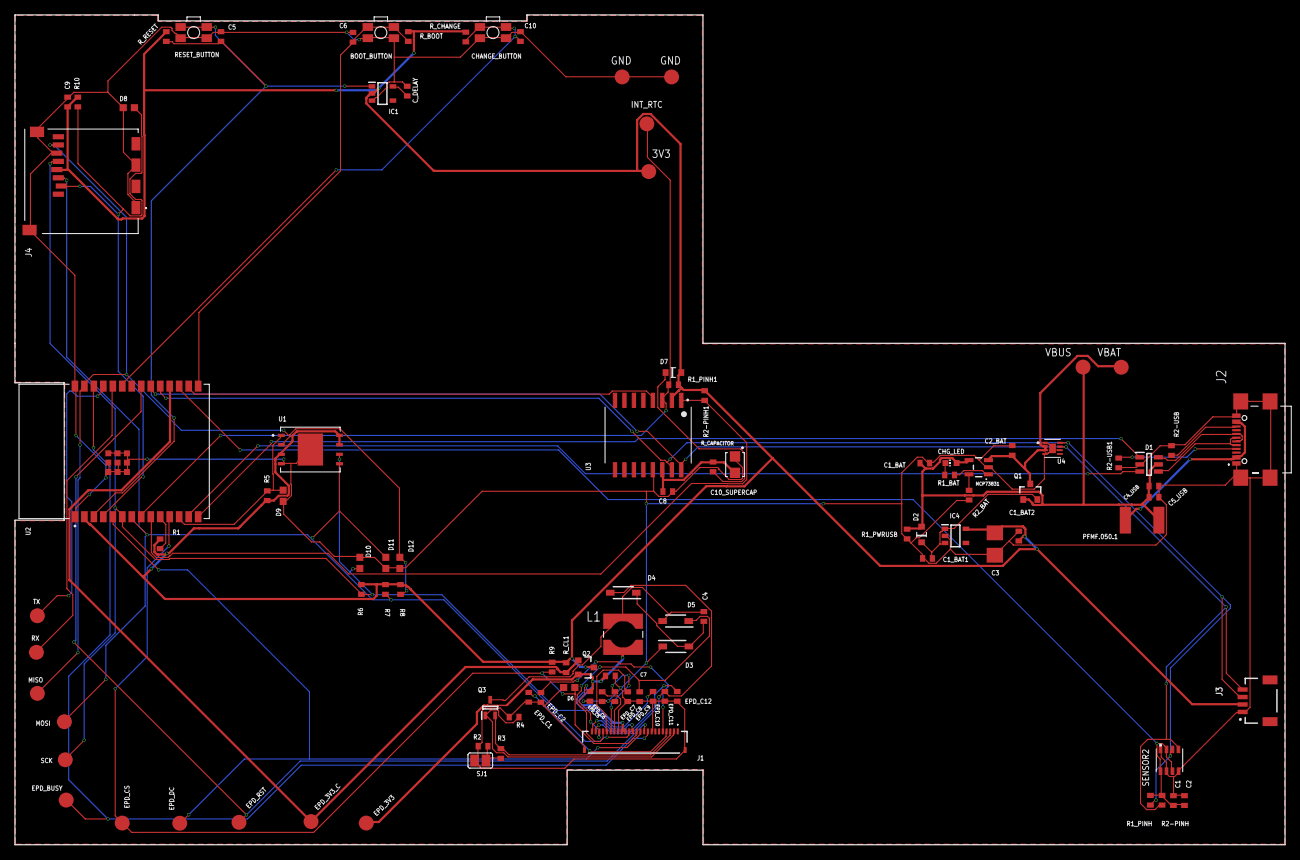
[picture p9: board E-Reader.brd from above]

Board: 2 copper layers, 170.2 x 111.2 mm, 103 parts (0 on the bottom side), 55 nets.

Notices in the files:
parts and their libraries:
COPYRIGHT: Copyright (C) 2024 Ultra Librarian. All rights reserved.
